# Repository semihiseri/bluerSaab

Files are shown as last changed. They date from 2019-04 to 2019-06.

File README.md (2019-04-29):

# bluerSaab
An ESP32 Port of the great BlueSaab projects. What? Yes, I lack creativity.

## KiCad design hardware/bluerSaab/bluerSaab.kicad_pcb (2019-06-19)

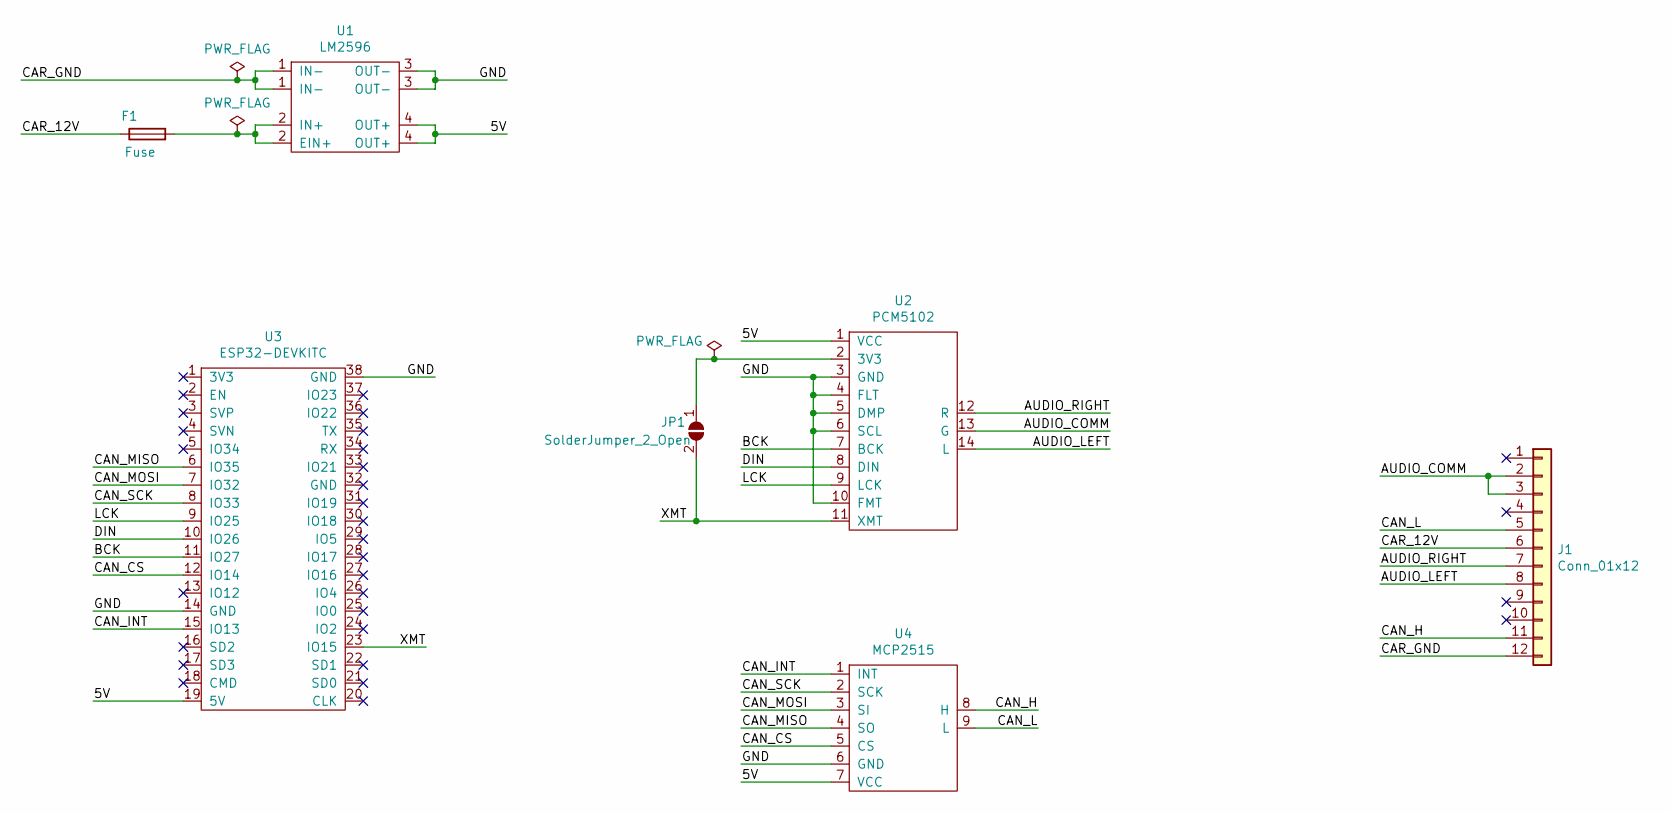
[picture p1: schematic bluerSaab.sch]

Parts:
F1: Fuse; Fuseholder_Fuse_TR5_Littlefuse-No560_No460
J1: Conn_01x12; SAAB_CDC
JP1: SolderJumper_2_Open; SolderJumper-2_P1.3mm_Open_TrianglePad1.0x1.5mm
U1: LM2596
U2: PCM5102
U3: ESP32-DEVKITC
U4: MCP2515

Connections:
/5V: U1.4 (OUT+), U2.1 (VCC), U3.19 (5V), U4.7 (VCC)
/AUDIO_COMM: J1.2, J1.3, U2.13 (G)
/AUDIO_LEFT: J1.8, U2.14 (L)
/AUDIO_RIGHT: J1.7, U2.12 (R)
/BCK: U2.7 (BCK), U3.11 (IO27)
/CAN_CS: U3.12 (IO14), U4.5 (CS)
/CAN_H: J1.11, U4.8 (H)
/CAN_INT: U3.15 (IO13), U4.1 (INT)
/CAN_L: J1.5, U4.9 (L)
/CAN_MISO: U3.6 (IO35), U4.4 (SO)
/CAN_MOSI: U3.7 (IO32), U4.3 (SI)
/CAN_SCK: U3.8 (IO33), U4.2 (SCK)
/CAR_12V: F1.1, J1.6
/CAR_GND: J1.12, U1.1 (IN-)
/DIN: U2.8 (DIN), U3.10 (IO26)
/GND: U1.3 (OUT-), U2.3 (GND), U2.4 (FLT), U2.5 (DMP), U2.6 (SCL), U2.10 (FMT), U3.14 (GND), U3.38 (GND), U4.6 (GND)
/LCK: U2.9 (LCK), U3.9 (IO25)
/XMT: JP1.2 (B), U2.11 (XMT), U3.23 (IO15)
unnamed: F1.2, U1.2 (EIN+)
unnamed: JP1.1 (A), U2.2 (3V3)

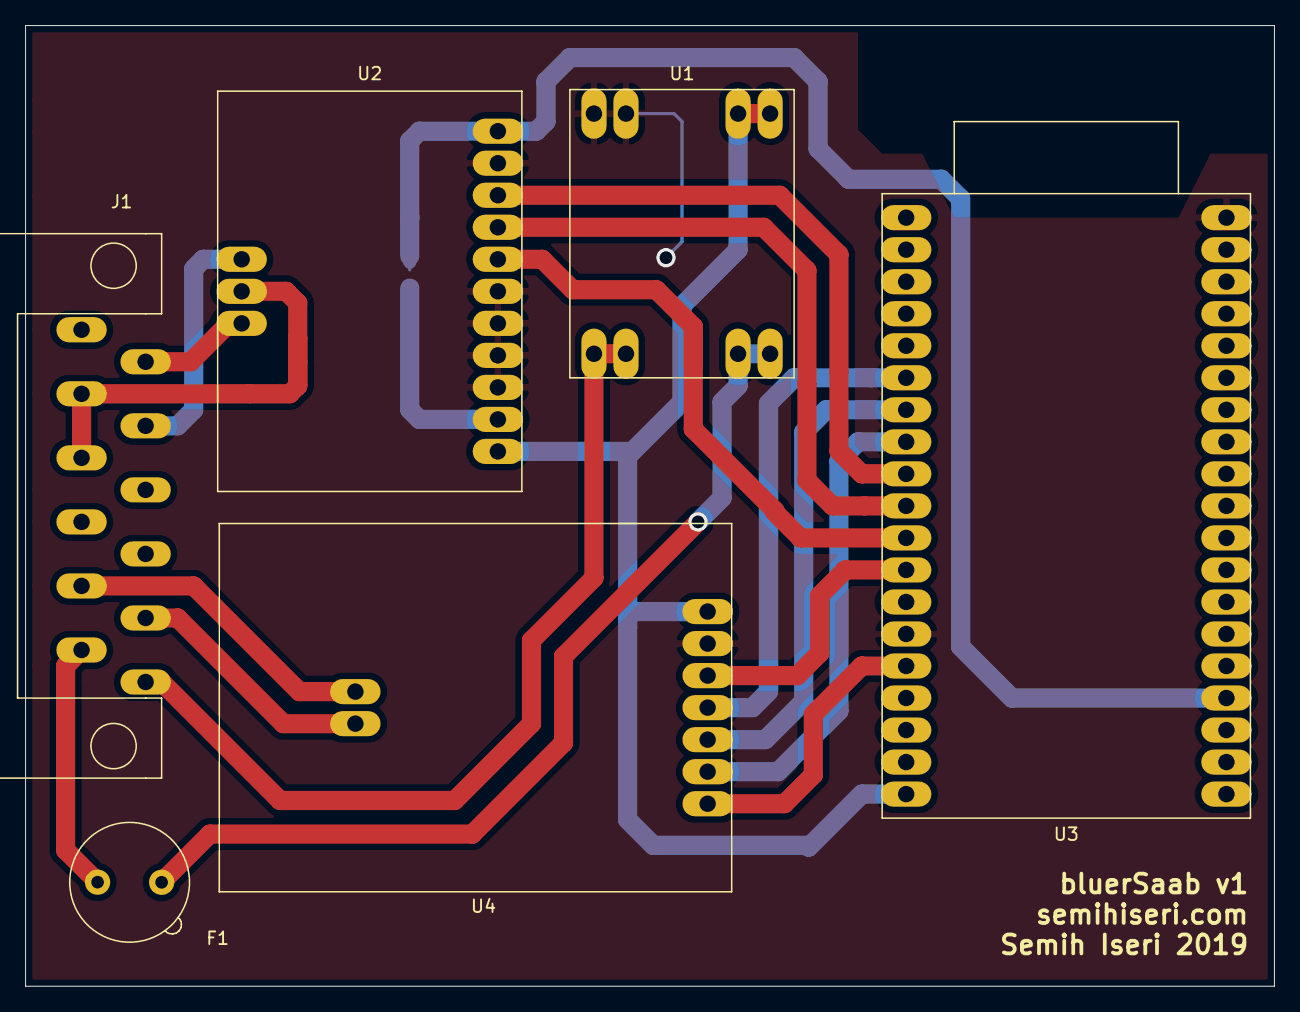
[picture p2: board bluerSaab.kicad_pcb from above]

Board: 2 copper layers, 99.1 x 76.2 mm, 7 parts (1 on the bottom side), 20 nets.

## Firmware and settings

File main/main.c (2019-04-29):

#include <stdio.h>
#include <stdlib.h>
#include <unistd.h>
#include <string.h>
#include "freertos/FreeRTOS.h"
#include "freertos/task.h"
#include "nvs.h"
#include "nvs_flash.h"
#include "esp_system.h"
#include "esp_log.h"


#include "driver/gpio.h"

//#include "bluetoothAudio.h"
#include "CAN.h"
#include "CDC.h"

TickType_t lastInterrupt;

#define ESP_INTR_FLAG_DEFAULT 0

#define MCP2515_INT GPIO_NUM_13

static void IRAM_ATTR gpio_isr_handler(void* arg)
{
	lastInterrupt = xTaskGetTickCount()*portTICK_RATE_MS/1000;
	return;
}

void sleeper()
{

	gpio_config_t io_conf;
	//disable interrupt
	io_conf.intr_type = GPIO_PIN_INTR_POSEDGE;
	//set as output mode
	io_conf.mode = GPIO_MODE_INPUT;
	//bit mask of the pins that you want to set,e.g.GPIO18/19
	io_conf.pin_bit_mask = 	(((uint64_t) 1)<<MCP2515_INT);
	//disable pull-down mode
	io_conf.pull_down_en = 0;
	//disable pull-up mode
	io_conf.pull_up_en = 0;
	//configure GPIO with the given settings
	gpio_config(&io_conf);

	//install gpio isr service
	gpio_install_isr_service(ESP_INTR_FLAG_DEFAULT);
	//hook isr handler for specific gpio pin
	gpio_isr_handler_add(MCP2515_INT, gpio_isr_handler, NULL);

	TickType_t now = xTaskGetTickCount()*portTICK_RATE_MS/1000;
	lastInterrupt = now;
	
	while (1)
	{
		now = xTaskGetTickCount()*portTICK_RATE_MS/1000;


		printf("sleeper: %d and %d\n", now, lastInterrupt);

		if (now-lastInterrupt > 10)
		{
			esp_sleep_enable_ext0_wakeup(MCP2515_INT, 0);
			esp_deep_sleep_start();
		}

		if (now-lastInterrupt > 5)
		{
			printf("Sleeping in %d seconds\n", 10-now+lastInterrupt);
		}

		vTaskDelay(1000 / portTICK_RATE_MS);
	}
}

void app_main()
{
//	startBluetooth();

	//printf("Now power the peripherals\n");
	//vTaskDelay(5000/portTICK_RATE_MS);
	//printf("Program started\n");


	//CAN_begin(47);
	CDC_openCanBus();

	xTaskCreate(&sleeper, "sleeper", 2048, NULL, 3, NULL);
	

	while(1)
	{

		CDC_handleCdcStatus();
	/*	printf("%s\n", getTitle());
		printf("%s\n", getArtist());*/
		vTaskDelay(1/portTICK_RATE_MS);
	}


	
   /* CDC.openCanBus();
while(1)
{
 CDC.handleCdcStatus();
}*/


}

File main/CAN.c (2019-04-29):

/*
 ----------------------------------------------------------------------------------
 CAN.cpp
 CONTROLLER AREA NETWORK (CAN 2.0A STANDARD ID)
 CAN BUS library for Wiring/Arduino - Version 1.1
 ADAPTED FROM http://www.kreatives-chaos.com
 By IGOR REAL (16 - 05 - 2011)
 ----------------------------------------------------------------------------------
 */
/*
 Name:
 Parameters(type):
 Description:
 Example:
 
 */
#include <stdio.h>
#include <stdlib.h>
#include <string.h>
#include "freertos/FreeRTOS.h"
#include "freertos/task.h"
#include "esp_system.h"
#include "driver/spi_master.h"
#include "soc/gpio_struct.h"

#include "sdkconfig.h" // why is this necessary?




#include "CAN.h"

#define DEBUGMODE	0


/******************************************************************************
 * Variables
 ******************************************************************************/
//CANClass CAN;

msgCAN CAN_TxMsg;
msgCAN CAN_RxMsg;


/******************************************************************************
 * Constructors
 ******************************************************************************/

#define MCP2515_CS	14
#define MCP2515_SCK	33
#define MCP2515_MOSI	32

#define MCP2515_MISO	35
#define MCP2515_INT	13

spi_device_handle_t spi;

/******************************************************************************
 * PUBLIC METHODS
 ******************************************************************************/
void CAN_begin(uint16_t speed)
{
    
#if (DEBUGMODE==1)
    printf("-- Constructor Can(uint16_t speed) --\n");
#endif


	gpio_config_t io_conf;
	//disable interrupt
	io_conf.intr_type = GPIO_PIN_INTR_DISABLE;
	//set as output mode
	io_conf.mode = GPIO_MODE_OUTPUT;
	//bit mask of the pins that you want to set,e.g.GPIO18/19
	io_conf.pin_bit_mask = 	(((uint64_t) 1)<<MCP2515_CS);
	//disable pull-down mode
	io_conf.pull_down_en = 0;
	//disable pull-up mode
	io_conf.pull_up_en = 0;
	//configure GPIO with the given settings
	gpio_config(&io_conf);

	esp_err_t ret;
	spi_bus_config_t buscfg={
		.miso_io_num=MCP2515_MISO,
		.mosi_io_num=MCP2515_MOSI,
		.sclk_io_num=MCP2515_SCK,
		.quadwp_io_num=-1,
		.quadhd_io_num=-1,
		.max_transfer_sz=16*320*2+8 // This can be adjusted, I guess. But not necessary.
		};

	spi_device_interface_config_t devcfg={
		.clock_speed_hz=8*1000*1000,           //Clock out at 8 MHz - maybe slower?
		.mode=0,                                //SPI mode 0
		.spics_io_num=-1,//MCP2515_CS,               //CS pin - we want total control, hence -1.
		.queue_size=7,                          //We want to be able to queue 7 transactions at a time
		};

	//Initialize the SPI bus
	ret=spi_bus_initialize(HSPI_HOST, &buscfg, 1);
	ESP_ERROR_CHECK(ret);

	//Attach the LCD to the SPI bus
	ret=spi_bus_add_device(HSPI_HOST, &devcfg, &spi);
	ESP_ERROR_CHECK(ret);


	

    
    // We activate the SPI Arduino as Master and Fosc/2=8 MHz
//    SPCR = (1<<SPE)|(1<<MSTR) | (0<<SPR1)|(0<<SPR0); // <-------------- ARDUINO Specific register!! Must kill!!
//    SPSR = (1<<SPI2X); // <-------------------------------------------- ARDUINO Specific register!! Must kill!!
#if (DEBUGMODE==1)
    printf("SPI=8 Mhz\n");
#endif
    
    
    
    // reset MCP2515 by software reset.
    // After this he is in configuration mode.
    RESET(MCP2515_CS);
    spi_putc(SPI_RESET);
    SET(MCP2515_CS);
    
    // wait a little bit until the MCP2515 has restarted
//    _delay_us(10);
	vTaskDelay(1 / portTICK_RATE_MS);
    
    
    
    switch(speed)
    {
        case 47:
            /*
             Supposed to use...?
             SJW = 1
             SP% ~= 75
            */
            //Original CNF values
             mcp2515_write_register(CNF1,0xC7);
             mcp2515_write_register(CNF2,0xBE);
             mcp2515_write_register(CNF3,0x04);
            /*
             T1   = 16
             T2   = 5
             BTQ  = 21
             SP%  = 76.19
             SJW  = 4
             Err% = 0
             */
            
            /*
             // Version 1
             mcp2515_write_register(CNF1,0x4B);
             mcp2515_write_register(CNF2,0xF1);
             mcp2515_write_register(CNF3,0x03);
             
             T1   = 14
             T2   = 7
             BTQ  = 21
             SP%  = 66.67
             SJW  = 4
             Err% = 0
             
             
             // Version 2
             mcp2515_write_register(CNF1,0xC7);
             mcp2515_write_register(CNF2,0xFE);
             mcp2515_write_register(CNF3,0x44);
             
             T1   = 16
             T2   = 8
             BTQ  = 24
             SP%  = 66.67
             SJW  = 1
             Err% = 0
             */
            /*
            // Version 3
            mcp2515_write_register(CNF1,0xC7);
            mcp2515_write_register(CNF2,0xBE);
            mcp2515_write_register(CNF3,0x44);
             T1   = 10
             T2   = 4
             BTQ  = 14
             SP%  = 71.4
             SJW  = 2
             Err% = 0
             */
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

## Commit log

2019-04-29 initial commit: mvp with reset & powersave & play
    [CAN.c]
2019-06-16 schematics with xmt
    [bluerSaab.kicad_pcb, bluerSaab.sch]
2019-06-16 Fuse added
    [bluerSaab.sch]
2019-06-17 footprints added
2019-06-17 Initial layout -missing footprints for conn and fuse
    [bluerSaab.kicad_pcb, bluerSaab.sch]
2019-06-17 some tracing done
    [bluerSaab.kicad_pcb, bluerSaab.sch]
2019-06-18 Footprints fixed, PCB done
    [bluerSaab.kicad_pcb]
2019-06-18 PCB minified to bring the size below 10x10cm
    [bluerSaab.kicad_pcb, bluerSaab.sch]
2019-06-19 Via sizes fixed
    [bluerSaab.kicad_pcb]
